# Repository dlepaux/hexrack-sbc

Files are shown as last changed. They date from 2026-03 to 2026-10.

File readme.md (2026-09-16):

# HexRack SBC

Modular 3D-printable honeycomb rack for cooling and mounting SBCs with a 92mm Noctua fan.

A stackable, parametric enclosure system designed in OpenSCAD. Each unit houses one SBC with board-specific back panels and connector cutouts. Features hexagonal shell design with voronoi ventilation patterns, dovetail rail system, and silent Noctua cooling.

## Supported Boards

- Rock 5B+
- Raspberry Pi 5 + Pironman 5 Max

## Project Structure

```
cad/                   OpenSCAD parametric design
  config.scad            Master configuration (dimensions, presets, tolerances)
  body.scad              Main entry point for rendering
  sections/body/         Body modules (face, fan, back, feet)
  components/            Reusable parts (rails, snap-fits, dovetails)
  lib/                   Helpers (shapes, honeycomb, screws, brackets)
  assets/                STL/SVG assets (fan model, voronoi pattern)
  SBC_Model_Framework/   Git submodule with precise SBC 3D models
website/                React + Three.js STL viewer and download portal
scripts/                STL generation pipeline
```

## Quick Start

### View & Download Parts

Visit the [live website](https://dlepaux.github.io/hexrack-sbc/) to preview 3D models and download STL files.

### Build Locally

```bash
# Install website dependencies
npm install

# Fetch the OpenSCAD WebAssembly runtime the configurator engraves with (~3MB, once)
./scripts/fetch-openscad-wasm.sh

# Dev server
npm run dev

# Generate STL files (requires OpenSCAD nightly)
chmod +x scripts/generate-stl.sh
./scripts/generate-stl.sh --local
```

### Requirements

- [OpenSCAD](https://openscad.org/downloads.html) (nightly recommended for Manifold backend)
- [Node.js](https://nodejs.org/) 22+ (for website)

## Hardware

Per unit, as counted from the CAD's hole patterns by `cad/hardware-export.scad`:

- **Fan**: Noctua NF-A9 PWM (92mm) — ×1, fixed with the 4 screws that come with it
- **M4×50 + M4 nut**: ×2, joining the front sections to the back
- **M3×10**: ×2, back panel
- **M2.5 heat-set inserts + M2.5 screws**: ×4 for Rock 5B+, ×7 for Pi 5 + Pironman 5 Max
- **SMA antenna post + nut**: ×2, only on units with WiFi antennas
- **Filament**: PLA, PETG (preferred)

Units joined into a rack need no extra fasteners — the intercase dovetail is entirely
printed. The [configurator](https://dlepaux.github.io/hexrack-sbc/) totals the hardware
for a whole rack.

## How It Works

Each unit is one SBC enclosure. The body is split into printable sections that snap together:

1. **Face** - Front panel with voronoi ventilation pattern
2. **Dust Filter** - Removable filter compartment, optionally engraved (see below)
3. **Fan Section** - 92mm Noctua mount with airflow channel
4. **Back Top** - Upper shell half with dovetail rails and diamond stacking keys for vertical/horizontal alignment
5. **Back Bottom** - Lower shell half with SBC mounting supports, screw pillars, and board-specific standoffs
6. **Feet** - Under units in a staggered column: an inverted triangle (default, open or closed) that continues the case's lower faces to the floor, an inverted pyramid that tapers the same way along the depth (prints upside down, with supports), an X flat on both the case and the floor (optionally on printed TPU pads), a half-cell that fills the gap between the neighbours and carries the face's vent pattern, or a tree trunk. Both slide into the back bottom's groove on a dovetail rail

The back panels are generated per-board configuration, so each unit gets precise mounting holes and connector openings for its specific SBC. Units stack on top of each other.

### Engraved labels

Each unit's dust filter can carry two engraved lines — a hostname, a rack position — cut
into the flat band between its two hexagons, which is the one outward-facing surface on
the assembled case that prints as a top face.

A label is per-unit, so it cannot be pre-built: CI publishes only the blank filter. The
configurator instead runs **real OpenSCAD, compiled to WebAssembly, in a Web Worker over
this repository's own `cad/` sources**, with the label passed as `-D`. That is the point
of carrying a 3MB runtime rather than doing the text in JavaScript: the mesh comes out of
the same Manifold engine and the same sources as every other published part, so an
engraved filter is the published one plus the text, not a lookalike. The browser's output
has been verified bit-identical to a native OpenSCAD render, vertex for vertex.

The runtime is fetched only when a label is actually set, so an unlabelled configuration
downloads nothing extra.

The limit on a label is a **width in millimetres, not a character count** — `dustLabelCutter()`
derives it from the hexagon band and publishes it as `manifest.labelLimit`. "NODE-01-RACK-A-XY"
and "NODE-01-RACK-ABCD" are both 17 characters and span 70.8mm and 74.1mm. Past the limit
the glyphs run off the flat and quietly stop cutting, so the field measures the real text
in the real font and the CAD asserts it again during the render.

## CI/CD

Pushing to `main` triggers GitHub Actions which:
1. Generates all STL files with OpenSCAD
2. Builds the React website
3. Deploys to GitHub Pages

## License

[CC BY-NC-SA 4.0](license.md) - David Lepaux

You are free to share and adapt this work for non-commercial purposes, with attribution and under the same license.

For commercial licensing inquiries, reach out at [david.lepaux.com](https://david.lepaux.com).

The site also serves two unmodified third-party components under their own terms: the
OpenSCAD WebAssembly build (GPL-2.0 with the CGAL linking exception) and Liberation Sans
Bold (SIL OFL 1.1). Notices and licence texts are in [`public/licences/`](public/licences/).

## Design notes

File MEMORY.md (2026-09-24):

- [Board is Kaneo HR](memory/board-is-kaneo-hr.md) — cards on Kaneo board `HR` via the `kaneo` MCP; Vikunja/altiplano retired 2026-09-24
- [Close tracker tasks only after landing](memory/close-tracker-tasks-only-after-landing.md) — HR-1 was closed once with only the CAD half done

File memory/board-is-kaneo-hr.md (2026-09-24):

---
name: board-is-kaneo-hr
description: Hexrack's cards live on Kaneo, board `HR`, through the `kaneo` MCP; Vikunja and altiplano are retired
metadata:
  type: reference
---

Hexrack's work is tracked on **Kaneo** (`kaneo.lepaux.com`), board **`HR`**, through the
**`kaneo` MCP**. It switched from Vikunja on 2026-09-24 (homelab HL-198), and card numbers
carried over: HR-1 is still HR-1.

- Resolve the board by its slug with `list_projects` (one workspace,
  `XlLKvDCbGviImqZEWeWDsXxM2p5qgdMv`). Tools take a card's cuid, never its number: find it
  with `search` (the number alone, e.g. `HR-1`, or title words alone, never both) or
  `list_tasks`.
- Columns: `to-do` → `doing` → `done`. Close with `update_task_status(done)`, after
  [[close-tracker-tasks-only-after-landing]].
- **Do not read Vikunja.** Its Hexrack project is archived and refuses writes, and the
  `altiplano` MCP that reached it is gone from every config. Each migrated comment's first
  line keeps its `[vikunja #N]` id.

**Why:** this file used to say the tracker's MCP was named `altiplano`. Since the switch,
that advice would send a session to a retired server, or to a board that no longer takes
writes.

**How to apply:** use the `kaneo` tools. If they are missing, run `claude mcp list` in the
directory the session was launched from. The workspace's `.mcp.json` provides kaneo, and MCP
tools only register at session start, so a server added mid-session needs a restart.

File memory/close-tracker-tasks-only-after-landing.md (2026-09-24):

---
name: close-tracker-tasks-only-after-landing
description: Close a board card when the work has actually landed and CI is green, not when the code is written
metadata:
  type: feedback
---

Do not mark a board card done because the implementation exists. Close it when the
work has landed on `main` and the deploy is green.

**Why:** HR-1 "Add dynamic engraving" was marked done at 12:11 on 2026-09-02 and had to
be reopened the same day — only the design decision and its CAD prerequisite had landed;
no configurator field, no worker, no wasm existed. The task's own description carries that
correction, which is how the mistake became visible at all. A task closed on "the code is
written" hides remaining work behind a green checkbox, and on this repo the gap between
written and shipped is a 7-minute Actions run that regenerates 131 STLs and can fail.

**How to apply:** after committing, push and watch the run (`gh run watch <id>
--exit-status`). Comment the commit SHA and the run id on the card while it builds, then
move it to `done` (`update_task_status`) only once it succeeds. If it fails, the task was never done. Uncommitted work
on a feature branch is not done either, however well tested.

Related: [[board-is-kaneo-hr]].

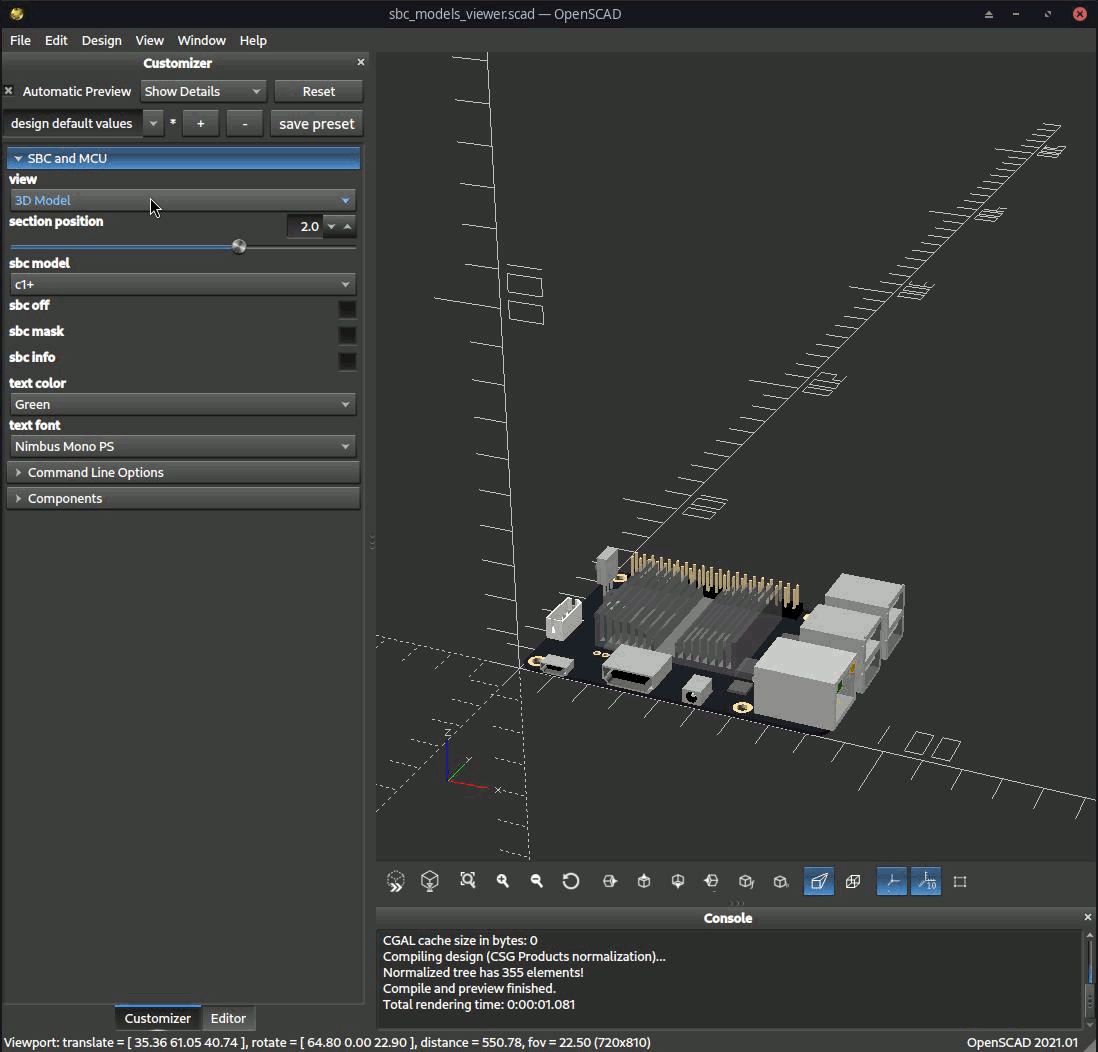
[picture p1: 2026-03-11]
cad/SBC_Model_Framework/sbc_models_viewer.gif

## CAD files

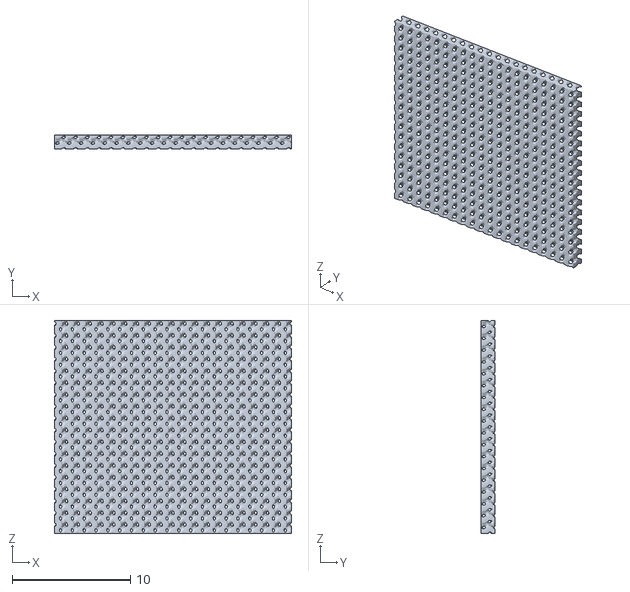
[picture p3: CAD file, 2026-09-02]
cad/assets/gyroid-tunnels.stl
20.0 x 1.21 x 18.0

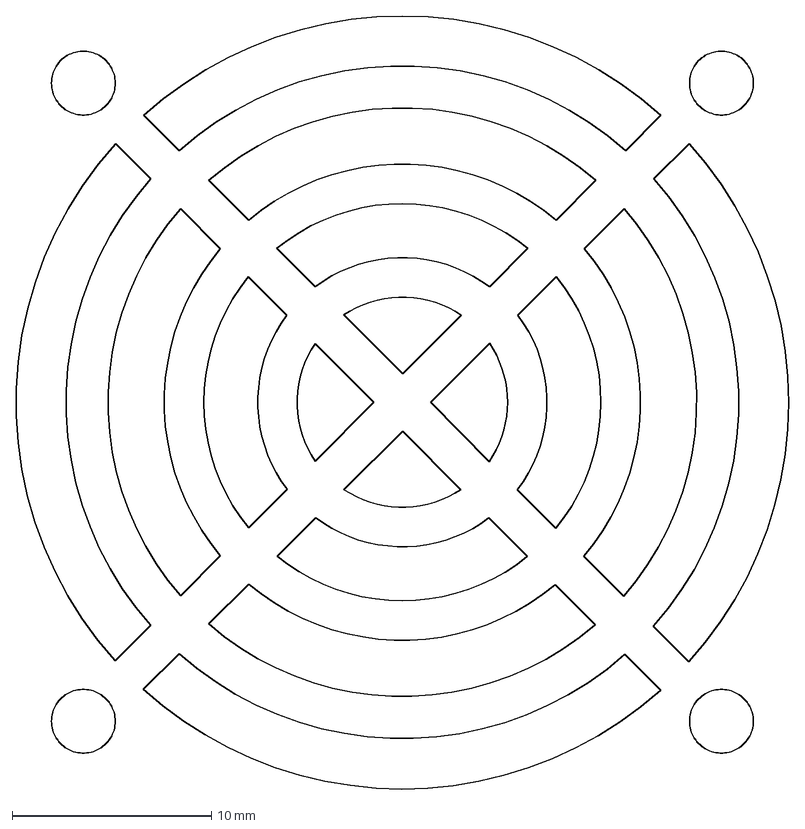
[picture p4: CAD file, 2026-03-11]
cad/SBC_Model_Framework/dxf/fan_40.dxf
38.7 x 38.8 mm

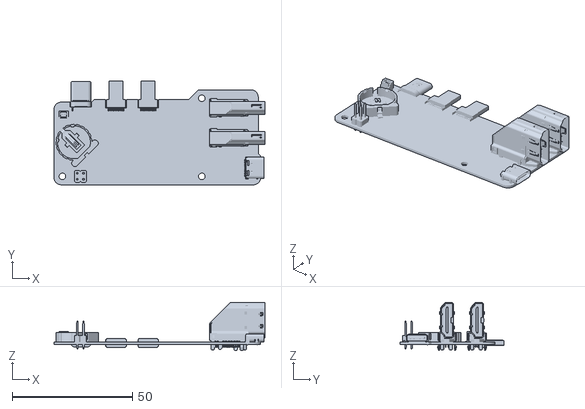
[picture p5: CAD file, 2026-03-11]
cad/assets/pironman-5-max-hdmi-usbc-adapter.stl
87.8 x 43.1 x 20.1

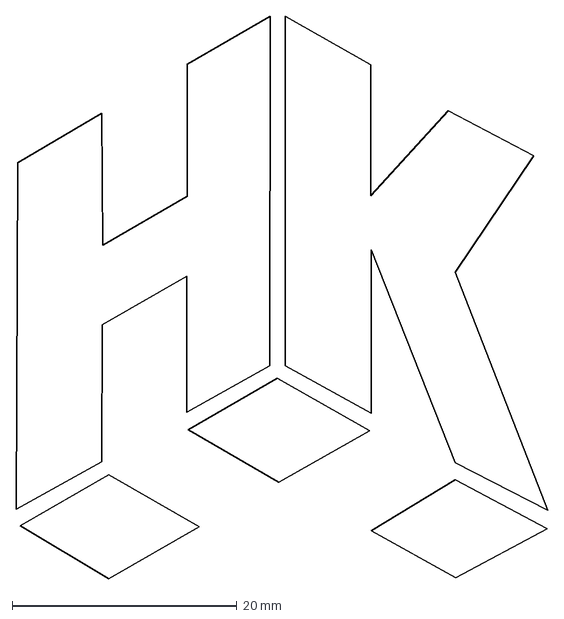
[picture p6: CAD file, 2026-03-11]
cad/SBC_Model_Framework/dxf/hk_50mm.dxf
47.3 x 50.0 mm

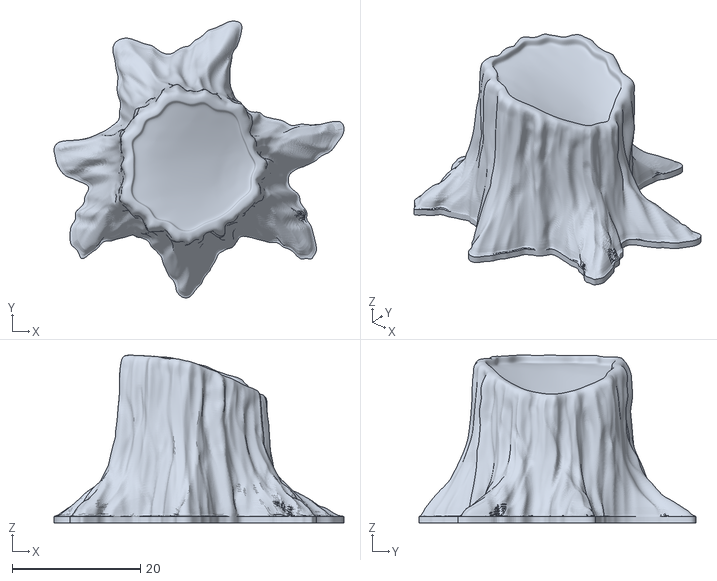
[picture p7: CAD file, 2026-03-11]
cad/assets/TreeTrunk.stl
45.3 x 43.2 x 26.2

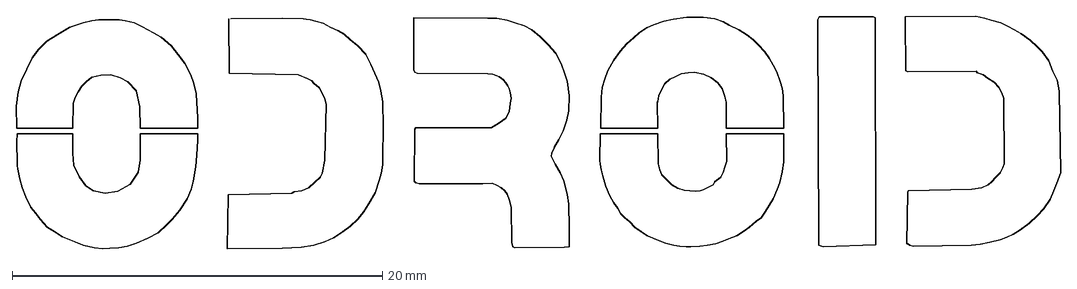
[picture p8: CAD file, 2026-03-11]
cad/SBC_Model_Framework/dxf/odroid.dxf
56.4 x 12.6 mm

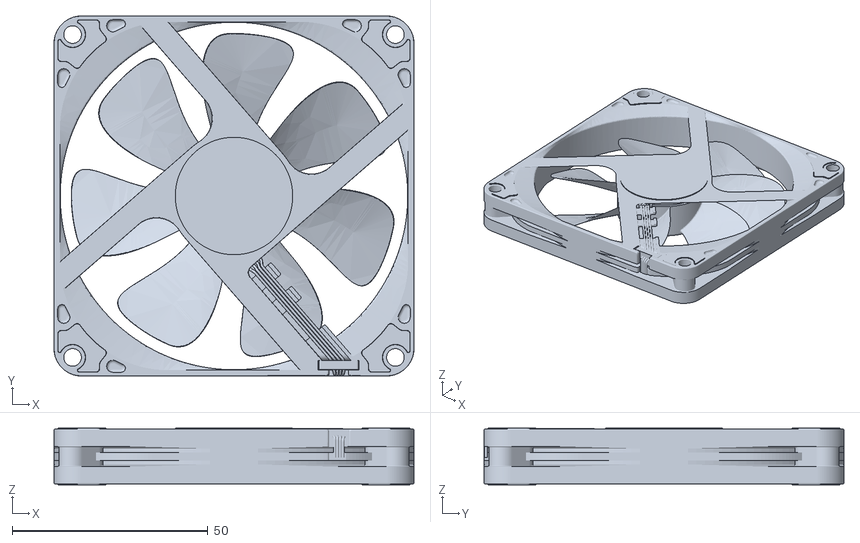
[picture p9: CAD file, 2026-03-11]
cad/assets/noctua-92.stl
92.0 x 92.0 x 14.5

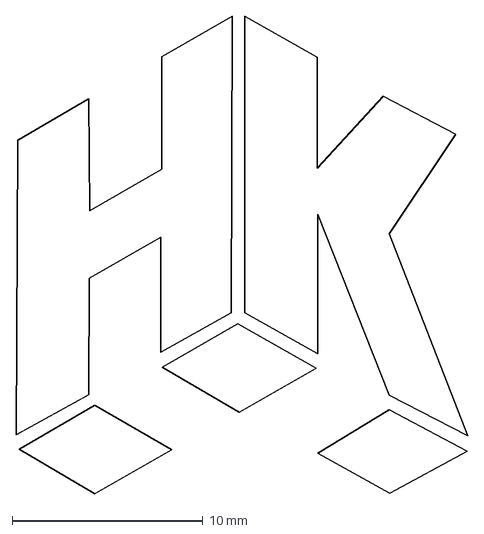
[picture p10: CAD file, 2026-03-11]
cad/SBC_Model_Framework/dxf/hk_25mm.dxf
23.7 x 25.0 mm

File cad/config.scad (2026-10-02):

// ============================================================================
// HEXRACK SBC - CONFIGURATION
// ============================================================================
// All parameters in one place for easy customization.
// Include this file in your .scad files: include <config.scad>
// ============================================================================

// ============================================================================
// GENERAL
// ============================================================================
EPS = 0.01;                // Small value for CSG operations (prevents z-fighting)
OVERLAP = 0.1;             // Overlap margin for panel connections
tolerance = 0.4;           // General fit tolerance

// Include screw specifications and API from lib/screws.scad
include <lib/screws.scad>

// ============================================================================
// BODY DIMENSIONS
// ============================================================================
body_width = 150;          // Width and height (square profile)
body_depth = 200;          // Depth (adjustable for final assembly)
// Back
back_depth = 115;
// Fan
fan_depth = 31; // Noctua 92mm

// --- Face section depth -----------------------------------------------------
// The face section holds the dust filter at its front and the vent panel at its back,
// so its depth is the sum of the two plus fit. It is DERIVED rather than typed, because
// the gyroid pattern needs a panel one full tunnel-turn deep and getting the two out of
// step leaves the panel either clipped or rattling.
//
// Sized for the SELECTED panel. This used to take max(face_thickness, gyroid_period), so
// every case was as deep as the gyroid needs (15.3mm) whatever pattern was chosen -- the
// flat patterns carried 9mm of dead plenum, and the case was 164.3mm instead of 155.3mm.
//
// The rejected argument for the max() was that a cosmetic choice must not change the case
// depth or units would not line up. It does not hold here: the vent pattern is a GLOBAL
// choice in the configurator, not per-unit, so a rack is all one depth either way. What it
// does mean is that depth is no longer one number -- caseDepth, the section offsets and the
// M4 stack screw all now depend on the pattern, and every one of them is derived from
// face_depth rather than typed, so they follow it. See cad/layout-export.scad.
//
// These must precede face_depth. OpenSCAD does NOT resolve forward references at file
// scope -- a variable used before its assignment reads as undef, SILENTLY. That is not
// theoretical here: with face_vent_pattern left at its old position further down this file,
// face_panel_thickness() below reads undef and quietly returns face_thickness for every
// pattern, gyroid included, and -D does not help because -D lands where the original
// assignment was.
dust_filter_depth = 4 - OVERLAP;   // sectionDust()'s default depth

// The dust filter's retaining ribs and the face's receiving grooves are ONE joint seen
// from two parts, so the plane they meet on is defined here and read by both. It is
// anchored to the FRONT of the case, where the filter actually seats.
//
// It must NEVER be anchored to face_depth. face_depth is sized for the deepest panel any
// pattern needs (below), so when the gyroid raised that from 2mm to 11mm, a groove written
// as "face_depth - 2" moved 9mm back and stopped meeting the rib at all -- on every
// pattern, gyroid included. Both parts still exported clean and the assembly still
// rendered; the joint had simply ceased to exist. scripts/test-dust-clip-fit.sh now
// measures the overlap instead of trusting it.
//
// dust_clip_clearance is how far behind the rib the groove sits, so the filter can slide
// in and the rib bite. tolerance + OVERLAP reproduces the fit the joint had before the
// gyroid: OVERLAP is a glue allowance dust_filter_depth subtracts at the BACK of the
// filter, and the seat at the front must not inherit it.
dust_clip_length    = 1.7;         // 45-degree rib, square section
dust_clip_y         = dust_filter_depth - sqrt(2) * dust_clip_length;
dust_clip_clearance = tolerance + OVERLAP;
face_thickness = 2;                // panel depth for voronoi / triangles / grid
// THE gyroid knob: how big one tunnel is. The panel is exactly one period deep, so this
// sets the case depth too -- there is no second knob and no free depth to choose.
//
// The panel MUST span a whole period. That is structural, not aesthetic: the gyroid's
// material is a single connected network only over a full period, and a partial slice
// cuts it into islands. Measured on this panel -- 1.0 turn: one body; 0.7: three bodies;
// 0.6: seven; 0.5: six. A fragmented panel still renders and exports clean, so nothing
// would have said so; scripts/test-vent-patterns.sh counts bodies for exactly this.
//
// NOT freely tunable, despite being a number. Whether the remaining web stays in ONE
// PIECE depends on how the cells happen to fall against the hexagon, its margin ring and
// the front circle -- and that does not vary smoothly. Measured, bodies as
// (front circle on / off):
//
//   period  8 -> 2 / 1      period 11 -> 1 / 1   <- the only value that holds both
//   period 10 -> 2 / 1      period 12 -> 2 / 1
//   period  9 -> 3 / -      period 13 -> 11 / 1
//
// A panel in two pieces renders and exports perfectly cleanly, so nothing in the build
// would say so -- it just falls apart coming off the bed. scripts/test-vent-patterns.sh
// counts bodies for every pattern crossed with the front circle. Change this number and
// run that test; do not assume a nearby value behaves like this one.
//
// At 11: 11mm panel, 164.3mm case, ~52,700 facets, 2.6MB, 2s.
face_vent_gyroid_period = 11;

// Which pattern the FRONT panel carries. Lives up here, not with the rest of the vent
// configuration, because face_depth below is derived from it -- see the ordering note above.
face_vent_pattern = "triangles";

// Panel depth for a given pattern. Only the gyroid varies through the depth, and it takes
// one whole period for the reason above.
function face_panel_thickness(mode = face_vent_pattern) =
    mode == "gyroid" ? face_vent_gyroid_period : face_thickness;

face_depth = dust_filter_depth + face_panel_thickness() + tolerance;
wall_thickness = 5;        // Wall thickness
corner_radius = 10;        // Radius for rounded corners (exterior)
inner_corner_radius = 6;   // Radius for rounded corners (interior)

// ============================================================================
// FAN SPECIFICATIONS (Noctua NF-A9 PWM 92mm)
// ============================================================================
fan_size = 92;            // Fan width and height (92x92mm)
fan_thickness = 30;        // Fan depth without anti-vibration pads
fan_with_pads = 32;        // Fan depth with anti-vibration pads
fan_extra_space = 1;       // Additional clearance for fan
fan_mount_hole_diameter = 4.3;  // Mounting hole diameter (4mm + tolerance)

// Fan mounting hole patterns (center to center distances)
fan_mount_71 = 71.5;  // 110 x 180 mm pattern (asymmetric)
fan_mount_82_5 = 82.5;     // 92mm fan square pattern (center to center)
fan_screw = "M5-Noctua";   // Screw spec the fan mounting holes are cut with

// Half-pitch of the fan screw square: panel center to a hole, per axis.
// The cable notches in the fan web are sized off this, so the two must not be
// allowed to drift apart. Returns 0 for a fan size with no known pattern --
// callers assert on that rather than silently stacking holes at the center.
function fan_screw_offset(mode) =
    mode == 92 ? fan_mount_82_5 / 2 :
    mode == 80 ? fan_mount_71 / 2 :
    0;

pironman_offset_for_nvme = 7;
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

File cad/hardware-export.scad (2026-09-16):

// ============================================================================
// HARDWARE EXPORT
// ============================================================================
// Emits how many of each fastener one case takes, counted from the same position lists
// the geometry cuts its holes from.
//
// scripts/generate-stl.sh used to write these into the manifest by hand, and they drifted:
// it published four M4 and eight M3 screws per case against the two of each the CAD cuts,
// and four inserts for every board when the Pironman adapter adds three more. Counting
// here means a hole added to a pattern is a screw added to the build sheet.
//
// Usage: openscad -o out.echo --export-format=echo -D 'drawer_board="rock5b+"' \
//          cad/hardware-export.scad
// ============================================================================

include <config.scad>
use <lib/shapes.scad>
use <lib/sbc-helpers.scad>
use <components/mounting-holes.scad>
use <SBC_Model_Framework/sbc_models.scad>
include <SBC_Model_Framework/sbc_models.cfg>

body_height = hex_flat_to_flat(body_width);

echo(str("HEXRACK_HARDWARE",
         " board=",        drawer_board,
         // M4 through the front sections, nut in the back halves' traps
         " stack=",        len(frontface_mounting_positions(body_height)),
         // M3 from the back face into the back halves, on the same pattern
         " backPanel=",    len(frontface_mounting_positions(body_height)),
         " fanScrews=",    len(fan_mounting_positions()),
         // One heat-set insert per supported board hole, adapter holes included
         " inserts=",      len(get_sbcMountingHoles(drawer_board)),
         " antennaPosts=", len(antenna_sides)));

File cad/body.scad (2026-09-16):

include <config.scad>
use <lib/shapes.scad>
use <components/fan.scad>
use <components/drawers.scad>

use <SBC_Model_Framework/sbc_models.scad>
include <SBC_Model_Framework/sbc_models.cfg>

use <lib/sbc-helpers.scad>
use <lib/pironman-base.scad>

use <sections/body/face.scad>
use <sections/body/fan.scad>
use <sections/body/back.scad>
use <sections/body/back-top.scad>
use <sections/body/back-face.scad>
use <sections/body/back-bottom.scad>
use <sections/body/dust.scad>
use <sections/body/feet.scad>
use <sections/body/top-supports.scad>

if (body_part == "assembly") {
  translate([0, -bodyAssembly_space, 0])
  sectionDust();

  translate([0, 0, 0])
  sectionFace();

  translate([0, face_depth + bodyAssembly_space, 0])
  sectionFan();

  translate([0, face_depth + fan_depth + bodyAssembly_space*2, 0])
  sectionBack();
}

if (body_part == "face_dust") {
  translate([0, 0, 0])
  sectionFace();

  translate([0, 0 + OVERLAP, 0])
  sectionDust();
}
if (body_part == "top-supports") {
  translate([0, 0, 0])
  sectionTopSupports();
}
if (body_part == "dust") {
  translate([0, 0, 0])
  sectionDust();
}
if (body_part == "fan") {
  translate([0, 0, 0])
  sectionFan();
}
if (body_part == "face") {
  translate([0, 0, 0])
  sectionFace();
}
if (body_part == "feet") {
  translate([0, 0, 0])
  sectionFeet();
}
if (body_part == "feet-pad") {
  sectionFeetPads();
}
if (body_part == "back") {
  translate([0, 0, 0])
  sectionBack();
}
if (body_part == "back-top") {
  translate([0, 0, 0])
  sectionBackTop();
}
if (body_part == "back-face") {
  translate([0, 0, 0])
  sectionBackFace();
}
if (body_part == "back-bottom") {
  translate([0, 0, 0])
  sectionBackBottom();
}

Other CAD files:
cad/layout-export.scad
cad/SBC_Model_Framework/sbc_models.scad
cad/SBC_Model_Framework/sbc_models_library.scad
cad/SBC_Model_Framework/sbc_models_viewer.scad
cad/components/antennas.scad
cad/components/dovetails.scad
cad/components/drawers.scad
cad/components/dust-filter.scad
cad/components/fan.scad
cad/components/mounting-holes.scad
cad/components/nuts.scad
cad/components/rails.scad
cad/components/snap-fit.scad
cad/sections/body/back-bottom.scad
cad/sections/body/back-face.scad
cad/sections/body/back-top.scad
cad/sections/body/back.scad
cad/sections/body/dust.scad
cad/sections/body/face.scad
cad/sections/body/fan.scad
cad/sections/body/feet.scad
cad/sections/body/top-supports.scad

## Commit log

2026-03-11 chore: first commit
    [TreeTrunk.stl, back-bottom.scad, back-face.scad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]
2026-05-08 feat(back-face): add optional WiFi antenna mount holes
    Add a toggleable pair of bulkhead antenna mounts to the back panel,
    symmetric around the port cutout. Cleanly drilled through-hole + hex
    nut trap captures a 6.2mm thread / 8mm AF connector body so the panel
    can hold the female mount torque-tight without a wrench inside.
    CAD:
    - New components/antennas.scad with antenna_hole_mask + visualization.
    - Reinforcement pad disc around each hole so the voronoi cutouts do
    not undermine the grip on the post.
    - New config block (enable_wifi_antennas, dimensions, placement,
    pad diameter, show_antennas preview).
    Pipeline & site:
    - generate-stl.sh emits two back-face STLs per board: base and
    -an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
    [antennas.scad, back-face.scad, config.scad]
2026-08-24 feat: improve frontface and dust support
    [body.scad, config.scad, dust.scad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]
2026-08-26 chore: add male/female to fit parts together
    [back-bottom.scad, back-face.scad, back-top.scad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]
2026-08-26 chore: add todo
    [back-bottom.scad, back-top.scad]
2026-08-27 feat: add top dovetails (sides not done)
    [back-bottom.scad, back-top.scad, config.scad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]
2026-08-27 feat(case dovetails): top and bottom clean
    [back-bottom.scad, back-top.scad, config.scad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]
2026-08-28 feat: adjustements
    [back-bottom.scad, back-face.scad, back-top.scad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]
2026-08-28 feat(face): add configurable front circle to the voronoi panel
    The front of the case had nothing echoing the fan bore sitting behind it.
    A solid band traced across the voronoi at the fan diameter draws that
    circle without opening a hole, so the panel keeps its full ventilation
    area — unlike the fan section's web, which is a true bore.
    The band is unioned after the SVG cutout so it refills the cells it
    crosses, and its diameter tracks fan_size_mode so the two stay concentric
    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
    [config.scad, face.scad]
2026-08-28 feat(scripts): generate every front-circle and dovetail variant
    Generation covered one fixed build, so the only way to get a case without
    protruding intercase dovetails — or without the new front circle — was to
    edit config.scad and render by hand.
    Both axes are now enumerated. They sit on disjoint parts, so they never
    multiply each other:
    face circle on/off
    back-top male dovetail subsets
    back-bottom, back-face female dovetail subsets
    Each part only ever reads the three faces on its own half of the case, so
    the complete set is the 8 subsets of one triple per part, not the 64
    subsets of all six faces. That is 66 STL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
2026-08-28 fix: address review findings on the variant matrix
    Empty zips. Every part in the three dovetails-* groups carries
    excludeFromDownloadAll, so PartGroup's filter left nothing and each group's
    "Download All" produced a zip holding one empty folder, silently. The flag
    exists to keep the site-wide zip lean; in a group that is nothing but
    alternates, the alternates are the content, so fall back to them.
    Mismatched dovetail pairs. back-face's front lip refills the last 3mm of
    every groove it does not carry through, so a Back Face and Back Bottom
    printed with different masks leaves a groove no neighbour's rail can enter.
    The two were published as freely pickable variants with nothing saying they
    mu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
2026-08-30 feat(fan): add cable notches to the fan web
    The fan drops into the web's bore and lands on its four frame corners, so
    its cable had no path through to the case interior. It could only be
    pinched under the frame or routed across the bore into the airflow.
    Four disc notches now bite into the bore edge, one per fan corner, at 90
    degree spacing. That spacing is the load-bearing invariant: the fan can be
    fitted in any of its four rotations and its one cable corner always meets
    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
    [config.scad, fan.scad, mounting-holes.scad]
2026-08-30 fix(test): report why the front circle render failed
    The suite has failed on every push to main since the front circle test was
    added on 28 Aug, and the whole step output was two lines: the header, then
    a bare exit code. render() discarded OpenSCAD's stderr, so set -e ended the
    run before any check could report, and the actual error was never written
    anywhere. The deploy has been blocked for two days behind an error nobody
    could see.
    A failing render now prints the OpenSCAD output, its version, and whether
    the voronoi asset and the SBC submodule are present, then exits. The
    oversize-diameter check reuses the same helper, since that one is meant to
    fail and must stay silent.
    This does not f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
2026-08-30 fix(test): keep the OpenSCAD work directory out of /tmp
    CI installs OpenSCAD from snap, which is strictly confined and gets its own
    private /tmp namespace. A work directory created by mktemp in the host's
    /tmp therefore does not exist as far as OpenSCAD is concerned: it refuses
    the output path with "is not a directory for output file", renders nothing,
    and exits non-zero. That is what has blocked the deploy since 28 Aug.
    Both suites now put their work directory beside the sources OpenSCAD
    already reads. The fan notch suite had the same latent bug and would have
    failed the same way the moment it got to run.
    Found only because the previous commit made the error visible.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
2026-08-31 fix: front face circle
    [config.scad, face.scad]
2026-08-31 chore: add vents
    [config.scad, face.scad]
2026-09-01 feat: add threaded inserts, improve sbc supports
    [back-bottom.scad, back-face.scad, config.scad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]
2026-09-01 feat: better sbc support
    [back-bottom.scad, config.scad, top-supports.scad]
2026-09-01 fix: use the right offset after rex
    [config.scad]
2026-09-01 feat(lips): shared snap-lip modules with a self-guiding, printable joint
    The tongue-and-groove joining the body sections was copy-pasted at nine sites
    across five files, with the 1.2/1.3 wall pair -- the actual fit -- duplicated at
    every one. Change it in one place and eight others silently disagree.
    Extract honeycombLipMale()/honeycombLipFemale() into lib/shapes.scad and hoist
    the fit to config. Two modules rather than one taking a type: a female call that
    lost its section_depth would cut the groove exactly where the tongue is and eat
    it, in a part that still renders and exports clean.
    The joint is an open rebate, not a closed groove -- the cutter reaches past the
    section's outer surface,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
    [back-bottom.scad, back-face.scad, back-top.scad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]
2026-09-02 fix(face): make front_circle_diameter real, and test material not triangles
    CI has been red since "chore: add vents" on two front-circle checks. Both were
    telling the truth about the code; neither was about the vents.
    front_circle_diameter and front_circle_band were dead. face.scad hardcoded
    center_hole=fan_size_mode, so setting the documented parameter did nothing and an
    out-of-range value rendered clean instead of tripping an assert -- roundedPanel has
    no guard of its own. The circle is the boundary between the solid rim and the
    vented centre, so past the flats there is no panel left to carry the rim. Wired the
    parameter through and asserted it fits. Default is fan_size_mode, so no geomet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
    [face.scad]
2026-09-02 feat(cad): dust filter labels, and a gyroid that actually tunnels
    ENGRAVING. dust_label_top / dust_label_bottom engrave into the 8.6mm band on the
    dust filter's front face -- the only flat, unbroken, outward-facing surface on the
    assembled case, and a top surface in the print orientation, so no overhang. Empty
    by default, so every published STL is byte-identical to before.
    OpenSCAD falls back silently when a font is missing, and text placed outside the
    band would cut into the ring's already-empty centre. Neither fails anything, so
    test-dust-label.sh measures instead: material must be removed, the envelope must
    not move, and the ring must stay one body.
    components/textover.scad and the whol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
    [config.scad, dust.scad, face.scad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]
2026-09-02 fix(build): keep the layout export in-tree, where snap OpenSCAD can see it
    CI failed at the manifest with "cad/layout-export.scad emitted no layout". The
    export wrote its echo file under the host's /tmp, and OpenSCAD installed from snap
    is strictly confined and gets a PRIVATE /tmp -- so it wrote nothing there, the grep
    found nothing, and the build stopped.
    Local macOS OpenSCAD is unconfined, so this passed every local run.
    The test scripts already carry this scar: scripts/test-front-circle.sh keeps its
    work directory beside the sources for exactly this reason. The layout export now
    does the same, under the .test-work.* name .gitignore already covers.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
    [config.scad, dust.scad]
2026-09-02 fix(cad): keep the gyroid off the back face at every entry point
    The gyroid is a front-face pattern. The back panel is back_face_thickness (3mm) and
    a gyroid needs a whole period of depth, so cutting one there leaves the panel in
    FIVE separate pieces -- which renders and exports perfectly cleanly.
    The substitution existed only in scripts/lib/variant-matrix.sh, which resolves it
    before rendering, so every published STL was already correct. But the rule was not
    in the model: opening cad/body.scad with body_part="back-face" and gyroid selected
    gave five pieces, and nothing said so. back_face_vent_pattern() now lives in
    config.scad and back-face.scad calls it, so the back face falls back wherev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
    [back-face.scad, config.scad]
2026-09-02 chore(cad): return the dust labels to their empty default
    A machine's LAN address and hostname reached the repo in 5fb54cd: config.scad had
    been edited locally to try the feature out, and a `git add -A` swept it in. Mine to
    catch, and I did not.
    Nothing is exposed that is not already private-range, and the published STLs never
    carried it -- generate-stl.sh forces the labels empty. But a shared default is the
    wrong place for one machine's name, and a fresh clone should render an unlabelled
    filter.
    Set labels locally and leave them uncommitted, the way cad/config.scad already
    carries an uncommitted bodyAssembly_space, or pass them per render:
    openscad -D 'dust_label_top="srv-core"' ...
    Th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
    [config.scad]
2026-09-02 fix(cad): size face_depth to the selected vent pattern, and reconnect the dust filter
    face_depth took max(face_thickness, face_vent_gyroid_period), so every case was as
    deep as the gyroid needs whatever pattern was chosen. The flat patterns carried 9mm of
    dead plenum and a 164.3mm case instead of 155.3mm. The argument for that was that a
    cosmetic choice must not change the case depth or units would not line up -- but the
    vent pattern is a GLOBAL choice in the configurator, not per-unit, so a rack is all one
    depth either way.
    Depth is therefore no longer one number, and three things followed from that.
    THE CLIP HAD ALREADY COME APART. face.scad anchored the dust filter's receiving groove
    to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
    [config.scad, dust.scad, face.scad]
2026-09-02 fix(face): clip the vent cutter to the front circle instead of unioning a ring over it
    The published body-face-gyroid.stl is broken, and has been since the gyroid landed. I
    downloaded it from the live site: 47860 triangles in 5 components. Four of those have a
    zero extent -- 2.3x0x1.4, 1.8x0x4.6, 7.7x0x5.7, 0.6x0x2.1 -- all lying at exactly
    y=4.3, the panel's front plane. They are not loose pieces of panel. They are
    zero-thickness sheets of triangles: degenerate CSG residue that prints as nothing,
    gets silently "repaired" by slicers, and renders as z-fighting shards in the site's
    WebGL preview, which is how it was noticed.
    They came from the front circle. It cut the pattern everywhere and t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
    [face.scad]
2026-09-02 chore: move the backlog to Vikunja and retire plan/
    The backlog now lives in the Hexrack project on Vikunja (9 open tasks, #1-#9),
    so plan/2026-09-02-rack-configurator.md goes. Reconciled item by item against
    HEAD first rather than migrated wholesale: 29 of its 37 checkboxes were already
    done and still marked open, including all of epic 1 and all of epic 2. Importing
    it as written would have produced a backlog that was wrong on its first day.
    The prose went too, and that is the part worth justifying. Two sections looked
    like knowledge worth keeping and were not:
    "The gyroid constraint" documents gyroidCutter()'s prism-slice method and its
    45-degree phase assert at vent-patterns.scad:17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
    [feet.scad]
2026-09-02 feat(engraving): cut per-unit dust filter labels in the browser
    Each unit's dust filter can now carry two engraved lines. A label is per-unit, so
    CI cannot pre-build it: the browser runs real OpenSCAD, compiled to WebAssembly,
    in a Web Worker over this repo's own cad/ sources, with the label passed as -D.
    That is the whole point of carrying a 3MB runtime rather than doing the text in
    JavaScript, and it was measured rather than assumed. The browser's mesh is
    bit-identical to a native OpenSCAD render of the same label: 1414 facets, 70784
    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
    [dust.scad]
2026-09-02 refactor(engraving): cut the label on download, not while typing
    Operator's call on the trade-off left open in 6eab4cb. Engraving is the expensive
    half of this feature -- an 11MB runtime and ~2s a label -- and firing it on a
    debounce spent that on every name tried on the way to the one actually kept.
    What made eager defensible was feedback, and feedback turns out not to need it.
    The label field measures its own width from the committed TTF and rejects an
    overlong label instantly, with no worker and no wasm; that is the check people
    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
2026-09-02 docs(memory): close tracker tasks only after the work lands
    HR-1 was marked done on 2026-09-02 at 12:11 and reopened the same day: only the
    design decision and the CAD prerequisite had landed, and the checkbox hid the
    rest. Recording the rule rather than the incident, since the gap between "the
    code is written" and "it shipped" on this repo is a 7-minute Actions run that
    regenerates 131 STLs and can fail.
2026-09-04 fix: back top bracket position
    [back-top.scad]
2026-09-08 fix: adapt rock5b+ back face
    [back-face.scad, config.scad]
2026-09-09 chore: fix z axis
    [config.scad]
2026-09-16 fix: thickness back face
    [config.scad]
2026-09-16 fix: cutout for dovetails
    [back-face.scad]
2026-09-16 chore: fix
    [back-face.scad]
2026-09-16 feat(feet): slide feet onto the dovetail and offer a triangle style
    The foot's diamond plug no longer locked into anything -- its sockets in
    back-top were commented out -- so a foot only sat under the case. It now
    carries the same "top" intercase rail a neighbour below would, running
    from the groove's stop to the case's back end: seated flush with the case,
    and flush on the end it prints standing on. Units on a foot take the
    matching bottom groove on Back Bottom and Back Face.
    The triangle continues a unit's two lower faces until they meet, which a
    hexagon puts exactly on the floor, so the rack reads as one honeycomb. It
    is 40 triangles against the trunk's 148k. The trunk stays as the defau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
    [config.scad, feet.scad, showcase.scad]
2026-09-16 feat(web): preview the configured rack live, default to triangle feet
    The hero showed a fixed three-unit showcase that matched nobody's rack. The
    aside now renders the rack being configured, assembled from the exact files
    the build sheet downloads: per-unit part resolution moved into unitParts(),
    shared by the sheet and the preview, so the two cannot disagree. Parts are
    placed from the manifest's grid pitch and section offsets, and the CAD now
    exports the feet offset the placement needed.
    With the showcase gone, its render, the per-board assembly STLs it imported
    and the manifest's assemblies key only cost CI time, so they are removed.
    The triangle becomes the default foot and takes body-f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
    [config.scad, feet.scad, layout-export.scad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]
2026-09-16 feat(web): landing page built around a drawing of a real rack
    The page opened on a title and four generic icon cards, which said little
    about what the rack is. The hero is now a front elevation of a three-cell
    rack drawn to the manifest's own dimensions, with the dovetails, fan and
    foot called out, followed by the configurator and the steps from download
    to shelf. Archivo is self-hosted so a visit makes no third-party request.
    Also adds a closed triangle foot: the same prism, solid, so its ends read
    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
    [config.scad, feet.scad]
2026-09-16 fix(hardware): count fasteners from the CAD's hole patterns
    The hardware list was hand-written when the configurator was built and never
    checked against the geometry: it published four M4 and eight M3 screws per
    case where the CAD cuts two of each, called the Noctua's own fan screws M5,
    and gave every board four inserts when the Pironman adapter adds three.
    The hole positions are now functions shared by the geometry and a new
    cad/hardware-export.scad, which the build reads per board, so a hole added to
    a pattern is a screw added to the build sheet. Insert counts are per board
    (hardware[].perBoard, hence manifest v5), and the manifest contract test
    fails on any count that disagrees with the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
    [back-face.scad, config.scad, hardware-export.scad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]
2026-09-16 feat(feet): add X, padded X and half-cell feet
    The triangle stands on a knife edge. The X keeps its line language but is
    flat on the case and flat on the floor; the padded X stops 1mm short and
    carries pockets for a TPU pads part, so the rack grips and damps without
    changing the drop. The half-cell fills the whole gap under a raised cell,
    flush with both neighbours less feet_side_clearance, and carries the face's
    vent pattern -- the same cutter placed as the missing cell -- so the rack
    closes into a complete honeycomb. It is built per vent pattern and resolves
    by it; the pads resolve with the padded foot.
    The fit test covers all six styles on both boards, now also against the two
    lower neig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
    [body.scad, config.scad, feet.scad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]
2026-09-16 feat(feet): add an inverted pyramid foot
    A new style beside the triangle, not a replacement: the triangle from the
    front and again from the side, so the case's bottom face tapers to a single
    point on the floor. It is the one foot that cannot print unsupported -- it
    prints upside down with supports under the hidden top face -- so the build
    sheet says so on that part. Its rail stops 1mm short of the back edge:
    flush, the rail met the top face exactly on that edge and the mesh was
    non-manifold.
    That defect was only caught by luck, so the fit test now checks every foot
    for non-manifold edges. It found the same kind of defect in the trunk, which
    predates this change and comes from cutting the im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
    [config.scad, feet.scad]
2026-09-24 docs(memory): Hexrack's board is Kaneo HR, not Vikunja through altiplano (HL-198)
    The Hexrack board switched from Vikunja to Kaneo on 2026-09-24, and the
    altiplano MCP is gone from every config. The memory that told sessions to look
    for altiplano would now send them to a retired server, or to an archived board
    that refuses writes. It is replaced by one that names the kaneo MCP, the HR
    slug and the cuid rule. The close-after-landing rule keeps its lesson and loses
    only the Vikunja wording.
2026-10-02 fix(test): pin LC_NUMERIC in the lip-fit suite
    Under fr_FR awk prints slab positions as 3,75 and OpenSCAD rejects the -D as
    a syntax error, so the suite failed on a French Mac and passed in CI.
2026-10-02 feat(dust): chamfer the filter window's front edge at 45 degrees
    A straight wall makes a square corner with the fabric where dust packs and
    will not wipe out. The chamfer opens toward the room.
    It shares the 8.6mm band with the engraved label, which was there first, so
    it takes what the label can spare: 2.0mm, leaving a 6.6mm flat for a 5mm
    label. The label is recentred on that flat and its width limit follows
    (61.2 -> 62.4mm). A smaller dust_label_size deepens the chamfer by itself.
    [config.scad, dust.scad]
2026-10-19 fix(back-top): make rear bracket flush with back_depth
    d7f3b07 moved the bracket 3mm back when 2mm made it flush, so it ended
    1mm past the section's rear edge and dug into the back face, out of
    plane with back-bottom's bracket. Both now use the back_depth datum.
    test-back-brackets.sh compares the two sections' depth so the offset
    cannot return silently; wired into CI.
